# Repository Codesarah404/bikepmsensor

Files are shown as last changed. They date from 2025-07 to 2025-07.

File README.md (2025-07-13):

# bikepmsensor
This project presents a portable air quality monitoring system for bicycles. It measures PM2.5 and PM10 in real time and transmits the data via LoRaWAN, helping cyclists choose healthier routes based on current pollution levels.

This project was originally developed as part of a master's thesis at **HTW Berlin (University of Applied Sciences)** in 2025.

---

## 📡 Features

- Real-time PM2.5 / PM10 monitoring with HM3301
- GPS-based location via u-blox NEO-6M
- LoRaWAN transmission (TTN compatible)
- OLED display for live data (PM-values/risk based on WHO air quality limits)
- RGB-LED traffic light

---

## 🔧 Hardware Used

- Heltec WiFi LoRa 32 V2 (ESP32 + LoRa + OLED + charging)
- HM3303 fine dust sensor
- DHT22 temperature and humidity sensor
- u-blox NEO-6M GPS module
- RGB LED
- LiPo battery

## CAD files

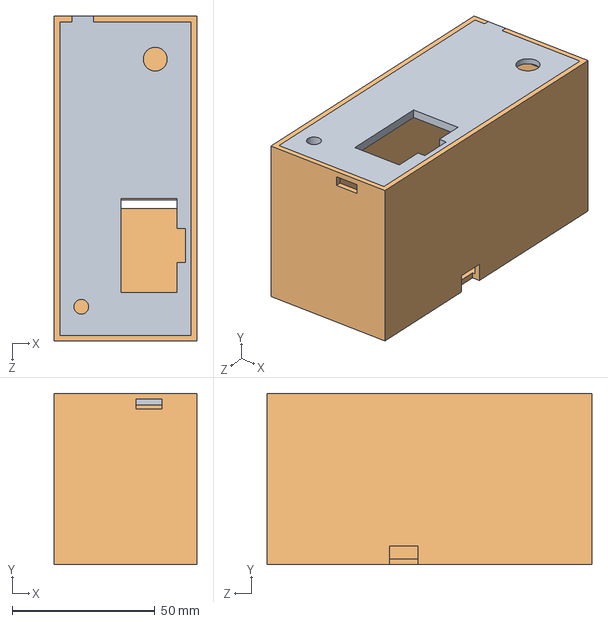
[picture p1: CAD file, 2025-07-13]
3d_printables/Gehäuse_gesamt.SLDASM
50.0 x 60.0 x 114.0 mm
Unterteil_Gehäuse
Oberteil_Gehäuse

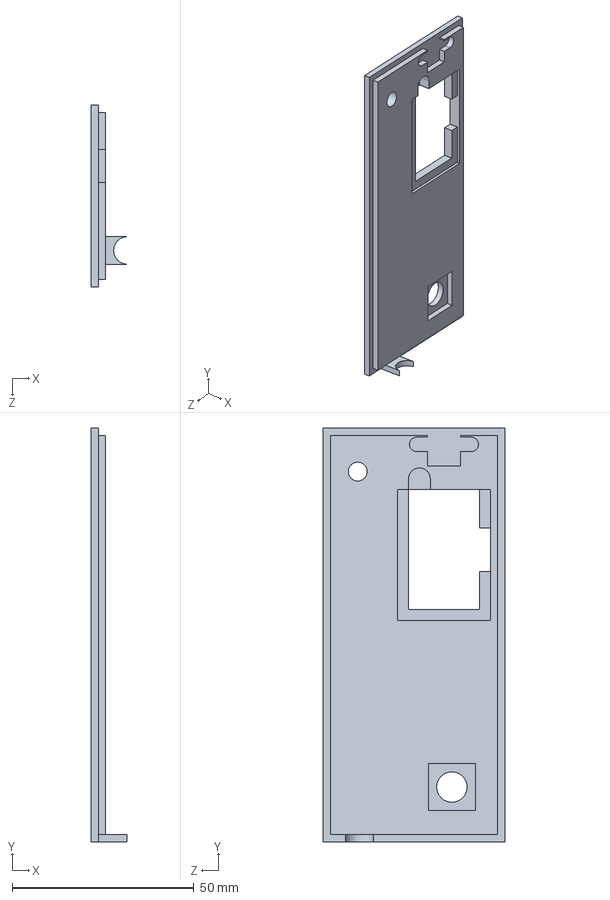
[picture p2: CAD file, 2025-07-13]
3d_printables/Oberteil_Gehäuse.SLDPRT
9.84 x 114.0 x 50.0 mm

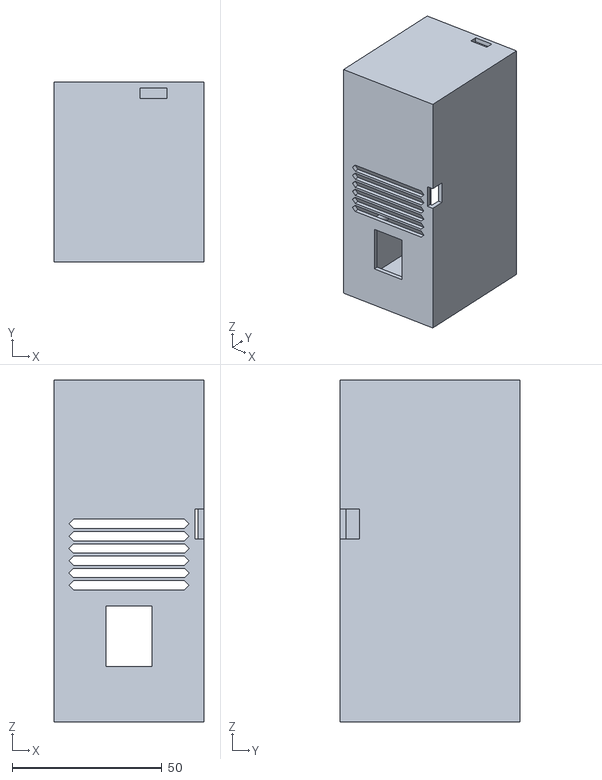
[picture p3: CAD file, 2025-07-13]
3d_printables/Unterteil_GehäuseV3.STL
50.0 x 60.0 x 114.0

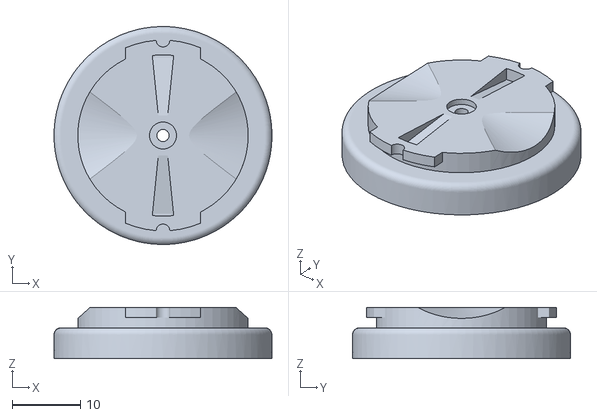
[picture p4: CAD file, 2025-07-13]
3d_printables/Garmin_Male_v2.STL
32.0 x 32.0 x 7.50

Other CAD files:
3d_printables/Oberteil_GehäuseV3.STL
3d_printables/Unterteil_Gehäuse.SLDPRT
3d_printables/Garmin_Male.SLDPRT

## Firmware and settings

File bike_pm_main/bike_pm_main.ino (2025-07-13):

/************************************************************************************************************************
Masterarbeit von Sarah Wauschkuhn,
Hochschule für Technik und Wirtschaft Berlin , 
2025

Hinweis: für das Projekt ist es im Vorfeld nötig einen Account bei TTN und Open Sensor Map anzulegen
TTN --> https://www.thethingsnetwork.org/docs/devices/registration/
Open Sensor Map --> https://opensensemap.org/register
Bitte prüfe deine LoRaWAN-Netzabdeckung für TTN -->  https://ttnmapper.org/heatmap/
Bitte prüfe bei Anpassung des Sendeintervalls, ob Fair Use Policy eingehalten wurde --> https://www.thethingsnetwork.org/airtime-calculator

Näheres hierzu ist in der dazugehörigen Masterthesis "Entwicklung eines Feinstaubmessgeräts für Radfahrende" zu finden.

Achtung ggf. C:\Users\name\Documents\Arduino\libraries\Heltec_ESP32_Dev-Boards\src\driver\sx1276.c in --> sx1276.c_backup umwandeln, macht sonst Probleme
************************************************************************************************************************/

//ESP32ChipID=9CD9A67A9834
// Basis-Bibliotheken für Arduino und Heltec
#include "Arduino.h"
#include <heltec.h>            // LoRa + OLED + ESP32-Funktionen (Heltec)

//für Heltec und Oled Display
#include "HT_SSD1306Wire.h"

//für HM3301 
#include <Tomoto_HM330X.h>
#include <Wire.h>

//für DHT11
#include <DHT.h>

//GPS
#include "HT_TinyGPS++.h"

//Lora
// LoRaWAN LMIC-Bibliotheken
#include <lmic.h>
#include <hal/hal.h>
#include <SPI.h>


//GPS
TinyGPSPlus gps;
//int year, month, day, hour, minute, second; //Zeit
double lat = 0.0, lon = 0.0; //Koordinaten
// GPS Pins definieren
#define GPS_RX 17  // Empfängt Daten vom GPS (GPS TX)
#define GPS_TX 12  // Sendet Daten an GPS (GPS RX)
HardwareSerial gpsSerial(2); // serial2 wird genutzt

// LoRa-Parameter (Europa)
// AppEUI, DevEUI und AppKey als Hex-Byte-Array (LSB-First)
static const u1_t PROGMEM APPEUI[8]  = { 0x00, 0x00, 0x00, 0x00, 0x00, 0x00, 0x00, 0x00 }; /* Füge eigene App EUI ein */ 
static const u1_t PROGMEM DEVEUI[8]  = { -, -, -, -, -, -, -, - }; /* Füge eigene Dev EUI ein, ist individuell und wird beim erstellen des Devices nach APPEUI generiert */ 
static const u1_t PROGMEM APPKEY[16] = { -, -, -, -, -, -, -, -,
                                         -, -, -, -, -, -, -, - }; /* Füge eigenen App Key ein */ 

const lmic_pinmap lmic_pins = {
  .nss = 18,      // LoRa_CS
  .rxtx = LMIC_UNUSED_PIN,
  .rst = 14,      // LoRa_RST
  .dio = {26, 35, 34}  // DIO0, DIO1, DIO2
};

static osjob_t sendjob;
//const unsigned TX_INTERVAL = 30; // ****Datenübertragung alle 30 Sekunden**** --> gut zum testen, doch kann das Netz schnell überlasten
//const unsigned TX_INTERVAL = 60; //****** Datenübertragung alle 60 Sekunden**** ---> Mittelweg, aber noch besser mehr Zeit geben
//const unsigned TX_INTERVAL = 120; // ****Datenübertragung alle 120 Sekunden****

unsigned long lastSensorRead = 0;
unsigned long lastDisplayUpdate = 0;
unsigned long lastSendTime = 0;

//Zeitmanagement, wichtig, da LoRa-Datenübertragung sehr getacktet ist. Die Prozesse des Devices müssen daher getaktet werden
const unsigned long sensorInterval = 5000;      // alle 5 Sekunden Sensoren auslesen
const unsigned long displayInterval = 2000;     // alle 2 Sekunden Display aktualisieren
const unsigned long sendInterval = 120000;      // alle 120 Sekunden senden

String loraStatusText = "";                // Text wie „Verbunden“, „Sende…“ etc.
unsigned long loraStatusTime = 0;          // Zeitpunkt der letzten Statusänderung
const unsigned long statusDisplayDuration = 4000;  // wie lange Status angezeigt wird (ms)

//HM330x - Feinstaub
//int pm1 = 0; //hierfür gibt es keine WHO Grenzwerte >> Falls doch gewünscht Programmversion mit pm1 wählen 
int pm25 = 0;
int pm10 = 0;
Tomoto_HM330X sensor;
//Achtung Standart für I2C kommunikation für heltec wifi lora v2! 
#define SDA 4
#define SCL 15

//DHT22
//#define DHT_PIN 13  > nicht verwenden Boot strap pin
#define DHT_PIN 25
#define DHT_TYPE DHT22       // DHT Typ, für DHT11 > #define DHT_TYPE DHT11   
DHT dht(DHT_PIN, DHT_TYPE);    // Initialisiere den DHT11 Sensor
float hum, temp;

//Warn-LED (RGB LED, Widerstände 120 OHM vor jedem PIN)
const int ledRotPin = 22;
const int ledGruenPin = 23;
const int ledBlauPin =13; 

//rotate only for GEOMETRY_128_64
#define SDA_OLED 4
#define SCL_OLED 15
#define RST_OLED 16
static SSD1306Wire  display(0x3c, 500000, SDA_OLED, SCL_OLED, GEOMETRY_128_64, RST_OLED); // addr , freq , i2c group , resolution , rst

//BitmapBild für Fahrrad erstellt mit GIMP
#define im_width 125
#define im_height 64
static unsigned char im_bits[] = {
   0xff, 0xff, 0xff, 0xff, 0xff, 0xff, 0xff, 0xff, 0xff, 0xff, 0xff, 0xff,
   0xff, 0xff, 0xff, 0x1f, 0xff, 0xff, 0xff, 0xff, 0xff, 0xff, 0xff, 0xff,
   0xff, 0xff, 0xff, 0xff, 0xff, 0xff, 0xff, 0x1f, 0xff, 0xff, 0xff, 0xff,
   0xff, 0xff, 0xff, 0xff, 0xff, 0xff, 0xff, 0xff, 0xff, 0xff, 0xff, 0x1f,
   0xff, 0xff, 0xff, 0xff, 0xff, 0xff, 0xff, 0xff, 0xff, 0xff, 0xcf, 0xff,
   0xff, 0xff, 0xff, 0x1f, 0xff, 0xff, 0xff, 0xff, 0xff, 0xff, 0xff, 0xff,
   0xff, 0xff, 0xc3, 0xff, 0xff, 0xff, 0xff, 0x1f, 0xff, 0xff, 0xff, 0xff,
   0xff, 0xff, 0xff, 0xff, 0xff, 0xff, 0xe1, 0xff, 0xff, 0xff, 0xff, 0x1f,
   0xff, 0xff, 0xff, 0xff, 0xff, 0xff, 0xff, 0xff, 0xff, 0x7f, 0xf0, 0xff,
   0xff, 0xff, 0xff, 0x1f, 0xff, 0xff, 0xff, 0xff, 0x1f, 0x00, 0xfe, 0xff,
   0xff, 0x3f, 0xfc, 0xff, 0xff, 0xff, 0xff, 0x1f, 0xff, 0xff, 0xff, 0xff,
   0x1f, 0x00, 0xfe, 0xff, 0xff, 0x1f, 0xfe, 0xff, 0xff, 0xff, 0xff, 0x1f,
   0xff, 0xff, 0xff, 0xff, 0x1f, 0x00, 0xfe, 0xff, 0xff, 0x1f, 0xff, 0xff,
   0xff, 0xff, 0xff, 0x1f, 0xff, 0xff, 0xff, 0xff, 0xff, 0xc7, 0xff, 0xff,
   0xff, 0x3f, 0xfe, 0xff, 0xff, 0xff, 0xff, 0x1f, 0xff, 0xff, 0xff, 0xff,
   0xff, 0xc7, 0xff, 0xff, 0xff, 0x3f, 0xfe, 0xff, 0xff, 0xff, 0xff, 0x1f,
   0xff, 0xff, 0xff, 0xff, 0xff, 0x8f, 0xff, 0xff, 0xff, 0x7f, 0xfe, 0xff,
   0xff, 0xff, 0xff, 0x1f, 0xff, 0xff, 0xff, 0xff, 0xff, 0x8f, 0xff, 0xff,
   0xff, 0x7f, 0xfc, 0xff, 0xff, 0xff, 0xff, 0x1f, 0xff, 0xff, 0xff, 0xff,
   0xff, 0x1f, 0xff, 0xff, 0xff, 0x7f, 0xfc, 0xff, 0xff, 0xff, 0xff, 0x1f,
   0xff, 0xff, 0xff, 0xff, 0xff, 0x1f, 0xff, 0xff, 0xff, 0x7f, 0xf8, 0xff,
   0xff, 0xff, 0xff, 0x1f, 0xff, 0xff, 0xff, 0xff, 0xff, 0x0f, 0xfe, 0xff,
   0xff, 0x3f, 0xf8, 0xff, 0xff, 0xff, 0xff, 0x1f, 0xff, 0xff, 0xff, 0xff,
   0xff, 0x0f, 0xfe, 0xff, 0xff, 0x3f, 0xf8, 0xff, 0xff, 0xff, 0xff, 0x1f,
   0xff, 0xff, 0xff, 0xff, 0xff, 0x47, 0xfc, 0xff, 0xff, 0x1f, 0xf1, 0xff,
   0xff, 0xff, 0xff, 0x1f, 0xff, 0xff, 0xff, 0xff, 0xff, 0xc7, 0xf8, 0xff,
   0xff, 0x8f, 0xf3, 0xff, 0xff, 0xff, 0xff, 0x1f, 0xff, 0xff, 0xff, 0xff,
   0xff, 0xe3, 0xf8, 0xff, 0xff, 0x87, 0xe3, 0xff, 0xff, 0xff, 0xff, 0x1f,
   0xff, 0xff, 0xff, 0xff, 0xff, 0xf3, 0xf1, 0xff, 0xff, 0xc7, 0xe3, 0xff,
   0xff, 0xff, 0xff, 0x1f, 0xff, 0xff, 0xff, 0x1f, 0xf8, 0xf1, 0xf3, 0xff,
   0xff, 0xe3, 0xc7, 0x81, 0xff, 0xff, 0xff, 0x1f, 0xff, 0xff, 0xff, 0x01,
   0x80, 0xf8, 0xe3, 0xff, 0xff, 0xf1, 0x07, 0x00, 0xf8, 0xff, 0xff, 0x1f,
   0xff, 0xff, 0x7f, 0x00, 0x00, 0xf8, 0xc7, 0xff, 0xff, 0xf1, 0x07, 0x00,
   0xe0, 0xff, 0xff, 0x1f, 0xff, 0xff, 0x1f, 0xf8, 0x1f, 0xf8, 0xc7, 0xff,
   0xff, 0xf8, 0x01, 0xff, 0x81, 0xff, 0xff, 0x1f, 0xff, 0xff, 0x0f, 0xff,
   0x7f, 0xf0, 0x8f, 0xff, 0x7f, 0xfc, 0x80, 0xff, 0x0f, 0xff, 0xff, 0x1f,
   0xff, 0xff, 0x87, 0xff, 0x3f, 0xe0, 0x8f, 0xff, 0x3f, 0x7e, 0x18, 0xff,
   0x1f, 0xfe, 0xff, 0x1f, 0xff, 0xff, 0xe3, 0xff, 0x3f, 0xc2, 0x1f, 0xff,
   0x3f, 0x3e, 0x1c, 0xff, 0x7f, 0xfc, 0xff, 0x1f, 0xff, 0xff, 0xf1, 0xff,
   0x1f, 0x8f, 0x1f, 0xff, 0x1f, 0x1f, 0x3f, 0xff, 0xff, 0xf8, 0xff, 0x1f,
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
  };


///////////////////////////////////////////////////////////////////////////////////////////////////////
//Startbildschirmprogramm1, Quelle: DrawingDemo der Heltec ESP32 Dev Boards Beispiele//////////////////
///////////////////////////////////////////////////////////////////////////////////////////////////////
void drawLines() {
  for (int16_t i=0; i<display.getWidth(); i+=4) {
    display.drawLine(0, 0, i, display.getHeight()-1);
    display.display();
    delay(10);
  }
  for (int16_t i=0; i<display.getHeight(); i+=4) {
    display.drawLine(0, 0, display.getWidth()-1, i);
    display.display();
    delay(10);
  }
  delay(250);

  display.clear();
}


///////////////////////////////////////////////////////////////////////////////////////////////////////
//Programmbildschirm - Anzeigesteuerung für OLED, ohne Lora-Status/////////////////////////////////////
///////////////////////////////////////////////////////////////////////////////////////////////////////
/*void showOLED(int pm25,int pm10, int hum, int temp){
    display.clear();
    display.setTextAlignment(TEXT_ALIGN_LEFT);
    display.setFont(ArialMT_Plain_10);

    //Feinstaubwerte festlegen
    display.drawString(0   , 0  ,   "PM");
    display.drawString(45  , 0  ,   "[ug/m^3]");
    display.drawString(0   , 16 ,   "PM2.5");
    display.drawString(56  , 16 ,   (String)pm25);
    display.drawString(0   , 32 ,   "PM10");
    display.drawString(56  , 32 ,   (String)pm10);

    //Risiko anzeigen
    display.drawString(94 , 0  ,  "RISIKO" );
    String pm25Risk = risikoPM25(pm25);
    display.drawString(94 , 16 ,    pm25Risk);
    String pm10Risk = risikoPM10(pm10);
    display.drawString(94 , 32 ,   pm10Risk);

    // Temperatur und Luftfeuchtigkeit anzeigen
    display.drawString(0   , 48 , "Temp: " + String((int)temp) + " °C");
    display.drawString(65   , 48 , "Hum: " + String((int)hum) + " %");

    //GPS ok, Lora ok, PM Failed ok
    //oder andere straße vorschlagen 
}*/

///////////////////////////////////////////////////////////////////////////////////////////////////////
//Programmbildschirm - Anzeigesteuerung für OLED, inklusive Lora-Status////////////////////////////////
///////////////////////////////////////////////////////////////////////////////////////////////////////
void showOLED(int pm25, int pm10, int hum, int temp) {
  display.clear();
  display.setTextAlignment(TEXT_ALIGN_LEFT); //Aussichtung 
  display.setFont(ArialMT_Plain_10); //Schriftart

  // Feinstaubwerte festlegen
  display.drawString(0   , 0  , "PM");
  display.drawString(45  , 0  , "[ug/m^3]");
  display.drawString(0   , 16 , "PM2.5");
  display.drawString(56  , 16 , (String)pm25);
  display.drawString(0   , 32 , "PM10");
  display.drawString(56  , 32 , (String)pm10);

  // Risiko anzeigen
  display.drawString(94 , 0  , "RISIKO");
  String pm25Risk = risikoPM25(pm25);
  display.drawString(94 , 16 , pm25Risk);
  String pm10Risk = risikoPM10(pm10);
  display.drawString(94 , 32 , pm10Risk);

  // Temperatur und Luftfeuchtigkeit anzeigen (leicht zusammengeschoben)
  //display.drawString(0   , 48 , "Temp: " + String((int)temp) + "°C");
  //display.drawString(60  , 48 , "Hum: " + String((int)hum) + "%");

  // -------- Temp, Hum 2. Version
  display.drawString(0   , 48 , "T: " + String((int)temp) + "°C");
  display.drawString(50  , 48 , "H: " + String((int)hum) + "%");

  /*//Variante 2 --- vorbereitet für Weiterentwicklung des Prototyps, verbesserte Fehlerbehandlung 
  // Feinstaubwerte festlegen
  display.drawString(0   , 0  , "PM");
  display.drawString(45  , 0  , "[ug/m^3]");

  // PM2.5
  display.drawString(0   , 16 , "PM2.5");
  display.drawString(56  , 16 , pm25 >= 0 ? String(pm25) : "---");

  // PM10
  display.drawString(0   , 32 , "PM10");
  display.drawString(56  , 32 , pm10 >= 0 ? String(pm10) : "---");

  // Risiko anzeigen
  display.drawString(94 , 0  , "RISIKO");
  display.drawString(94 , 16 , pm25 >= 0 ? risikoPM25(pm25) : "-");
  display.drawString(94 , 32 , pm10 >= 0 ? risikoPM10(pm10) : "-");

  // Temperatur und Luftfeuchtigkeit anzeigen
  display.drawString(0   , 48 , (temp >= -40 && temp <= 85) ? ("T: " + String((int)temp) + "°C") : "T: ---");
  display.drawString(50  , 48 , (hum >= 0 && hum <= 100) ? ("H: " + String((int)hum) + "%") : "H: ---");
  */


  // LoRa Status-Icon anzeigen, falls aktiv (rechts unten)
  if (millis() - loraStatusTime < statusDisplayDuration && loraStatusText != "") {
    display.setTextAlignment(TEXT_ALIGN_RIGHT);
    display.drawString(124, 48, getLoRaSymbol());  // Symbol z. B."..." oder "ok"
  }

  display.display();
}

///////////////////////////////////////////////////////////////////////////////////////////////////////
//Lorastatus für Programmbildschirm///////////////////////////////////////////////////////////////////
///////////////////////////////////////////////////////////////////////////////////////////////////////
String getLoRaSymbol() {
  if (loraStatusText.indexOf("Verbinde") >= 0) return "...";
  if (loraStatusText.indexOf("verbunden") >= 0) return "ok";
  if (loraStatusText.indexOf("fehlgeschl") >= 0) return "er";
  if (loraStatusText.indexOf("Sende") >= 0) return ">>";
  if (loraStatusText.indexOf("Upload") >= 0) return "up";
  return "no";
}

///////////////////////////////////////////////////////////////////////////////////////////////////////
// Funktion zur Bewertung des PM2.5-Risikos nach WHO-Richtlinien (2021)////////////////////////////////
///////////////////////////////////////////////////////////////////////////////////////////////////////
// Tagesmittelwerte:
// - ≤ 15 µg/m³ → gesundheitlich unbedenklich (grün)
// - 16–25 µg/m³ → leicht erhöhtes Risiko (gelb)
// - > 25 µg/m³ → gesundheitlich bedenklich (rot)
String risikoPM25(int pm25) {
  if (pm25 <= 15) {
    return "Niedrig";  // WHO-Grenzwert eingehalten
  } 
  else if (pm25 <= 25) {
    return "Mittel";   // Grenzwert leicht überschritten
  } 
  else {
    return "Hoch";     // Deutlich über WHO-Grenzwert
  }
}
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
void loop() {
  unsigned long now = millis();

  // GPS verarbeiten
  while (gpsSerial.available()) { //ist GPS da?
    gps.encode(gpsSerial.read());  // GPS-Daten kontinuierlich parsen (NMEA-Zeichenkette dekodieren)
  }
  if (gps.location.isValid()) { //sind die Daten gueltig?
    lat = gps.location.lat(); //Latitude extrahieren
    lon = gps.location.lng(); //Longitude extrahieren
  }

  // Sensoren auslesen
  if (now - lastSensorRead > sensorInterval) {
    lastSensorRead = now;

    // HM3301 auslesen
    if (!sensor.readSensor()) {
      Serial.println("HM3301 Fehler");
      pm25 = -1; //absichtlicher Fehler, da nicht möglich
      pm10 = -1; 
    } else {
      pm25 = sensor.std.getPM2_5(); //gibt int aus
      pm10 = sensor.std.getPM10(); //gibt int aus 
    }

    // DHT22 auslesen
    hum = dht.readHumidity();
    temp = dht.readTemperature();
    if (isnan(hum) || isnan(temp)) {
      hum = -1; //absichtlicher Fehler, unwahrscheinlich, dass alle Sensoren -1 ausgeben 
      temp = -1;
    }

    // RGB-LED-Farblogik zur visuellen Darstellung der Luftqualitätsstufen gemäß PM2.5- und PM10-Grenzwerten (WHO)
    if (pm25 <= 15 && pm10 <= 45) { //gruen
      digitalWrite(ledGruenPin, HIGH);
      digitalWrite(ledRotPin, LOW);
      digitalWrite(ledBlauPin, LOW);
    } else if (pm25 <= 25 && pm10 <= 75) {//gelb
      digitalWrite(ledGruenPin, HIGH);
      digitalWrite(ledRotPin, HIGH);
      digitalWrite(ledBlauPin, LOW);
    } else { //rot
      digitalWrite(ledGruenPin, LOW);
      digitalWrite(ledRotPin, HIGH);
      digitalWrite(ledBlauPin, LOW);
    }

    // Debug-Ausgabe
    /*Serial.print("GPS OK? "); Serial.println(gps.location.isValid() ? "JA" : "NEIN");
    Serial.print("PM2.5: "); Serial.println(pm25);
    Serial.print("PM10: "); Serial.println(pm10);
    Serial.print("Temp: "); Serial.println(temp);
    Serial.print("Hum: "); Serial.println(hum);
    Serial.print("Lat: "); Serial.println(lat, 6);
    Serial.print("Lon: "); Serial.println(lon, 6);
    Serial.print("Satelliten: "); Serial.println(gps.satellites.value());
    Serial.print("HDOP: "); Serial.println(gps.hdop.hdop());*/
  }

  // OLED-Anzeige aktualisieren, wenn das Intervall überschritten ist
  /*now -               Zeit die seit Start von millis() vergangen ist
   lastDisplayUpdate -  Der Zeitpunkt (in ms), an dem das Display zuletzt aktualisiert wurde
   displayIntervall -   Zeitpunkt wann Display das letzte mal aktualisiert wurde*/
  if (now - lastDisplayUpdate > displayInterval) {
    lastDisplayUpdate = now; 
    showOLED(pm25, pm10, hum, temp); // Sensorwerte auf dem Display anzeigen
    //display.display();
  }

  // LoRaWAN Daten senden
  if (now - lastSendTime > sendInterval) { // Prueft, ob seit dem letzten Sendezeitpunkt genug Zeit vergangen ist (Intervallsteuerung).
    lastSendTime = now; // Zeitstempel aktualisieren, um Intervallsteuerung zu ermoeglichen; verhindert mehrfaches Senden im selben Intervall
    do_send(&sendjob); // Sendevorgang starten: Payload wird vorbereitet und ueber LoRaWAN uebertragen; uebergibt einen Auftrag an LMIC, um Sensordaten als Payload ueber LoRaWAN zu uebertragen.
  }

  /*
  // Weiterentwicklung um Fehlerhafte Weiterleitung an OSEM auszuschließen
    // Prüfung auf die -1 bei ALLEN Sensoren vorliegt
    bool all_invalid = 
      (pm25 == -1) &&
      (pm10 == -1) &&
      (temp == -1) &&
      (hum == -1);

  if (now - lastSendTime > sendInterval) {
    lastSendTime = now;
    if (!all_invalid) {
        do_send(&sendjob);
    } else {
        Serial.println("Alle Sensorwerte ungültig, keine LoRa-Übertragung."); //Sendevorgang verhindern, falls ungültige Werte --> da Kontaktfehler; noch am Starten etc. 
    }
  }*/

  // LMIC weiterlaufen lassen
  os_runloop_once(); 
}

///////////////////////////////////////////////////////////////////////////////////////////////////////
// LMIC Sende-Funktion/////////////////////////////////////////////////////////////////////////////////
///////////////////////////////////////////////////////////////////////////////////////////////////////
void do_send(osjob_t* j) {
  if (LMIC.opmode & OP_TXRXPEND) { //Abfrage ob der LoRaWAN-Stack aktuell mit Senden oder Empfangen beschaeftigt ist (OP_TXRXPEND ist ein Bit-Flag)
    Serial.println("LoRa TX läuft noch...");
  } else {
    // Payload vorbereiten
    byte payload[14];  // 2x PM, 1x Temp, 1x RH, 2x GPS à 4 Bytes = 14

    // Feinstaub (PM2.5 & PM10)
    payload[0] = pm25 >> 8; //oberes Byte von pm25; ... >> N: Rechtsverschiebung – holt das Byte an Position N
    payload[1] = pm25 & 0xFF; //unteres Byte von pm25; ... & 0xFF: Maskiert alle Bits außer den unteren 8 (ein Byte)
    payload[2] = pm10 >> 8; //oberes Byte von pm10
    payload[3] = pm10 & 0xFF; //unteres Byte von pm10

    // Temperatur & Luftfeuchtigkeit (nur ganzzahlig, je 1 Byte)
    payload[4] = (int)temp;
    payload[5] = (int)hum;

    // GPS-Koordinaten in Mikrograd umwandeln
    int32_t lat_bin = lat * 1e6;  // z.B. 52.520008 → 52520008
    int32_t lon_bin = lon * 1e6;

    // Latitude (Big Endian)
    payload[6]  = (lat_bin >> 24) & 0xFF;// Byte 1 (höchstes)
    payload[7]  = (lat_bin >> 16) & 0xFF;
    payload[8]  = (lat_bin >> 8)  & 0xFF;
    payload[9]  =  lat_bin        & 0xFF;// Byte 4 (niedrigstes)

    // Longitude (Big Endian)
    payload[10] = (lon_bin >> 24) & 0xFF;// Byte 1 (höchstes)
    payload[11] = (lon_bin >> 16) & 0xFF;
    payload[12] = (lon_bin >> 8)  & 0xFF;
    payload[13] =  lon_bin        & 0xFF;// Byte 4 (niedrigstes)

    // Senden
    /*  1: LoRaWAN-Portnummer (in TTN entsprechend zugeordnet, z.B. für einen Payload-Decoder).
        payload: Pointer auf das zu sendende Byte-Array.
        sizeof(payload): Länge des Payloads in Bytes (hier 14).
        0: Unbestätigte Übertragung (kein ACK erforderlich) >> siehe TTN Fair Policy, sonst weniger Airtime am Tag moeglich*/
    LMIC_setTxData2(1, payload, sizeof(payload), 0);
    Serial.println("LoRaWAN Daten gesendet");
  }
}


///////////////////////////////////////////////////////////////////////////////////////////////////////
//Lora Event Handler///////////////////////////////////////////////////////////////////////////////////
///////////////////////////////////////////////////////////////////////////////////////////////////////
/*Event-Handler für die LoRaWAN-Bibliothek LMIC. Sie wird automatisch aufgerufen, wenn das LoRa-Modem 
ein bestimmtes Ereignis (event) meldet –z. B. Verbindungsaufbau, Datenübertragung, Fehlermeldung. 
Hier wird auf die verschiedenen LMIC-Ereignisse reagiert und entsprechende Meldungen auf dem seriellen
Monitor ausgegeben.*/
void onEvent(ev_t ev) {
  Serial.print("LMIC Event: ");
  Serial.println(ev); //gibt numerischen Wert des Events zur Diagnose aus

  switch (ev) {
    case EV_JOINING:
      Serial.println("Beitritt zu TTN läuft...");
      loraStatusText = "Verbinde mit TTN...";
      loraStatusTime = millis();
      break;

    case EV_JOINED:
      Serial.println("Erfolgreich mit TTN verbunden!");
      loraStatusText = "TTN verbunden";
      loraStatusTime = millis();
      // Optionale Link Check Abschaltung:
      LMIC_setLinkCheckMode(0);
      break;

    case EV_JOIN_FAILED:
      Serial.println("Beitritt zu TTN fehlgeschlagen!");
      loraStatusText = "TTN Join fehlgeschl";
      loraStatusTime = millis();
      break;

    case EV_TXSTART:
      Serial.println("Sende Daten...");
      loraStatusText = "Sende";
      loraStatusTime = millis();
      break;

    case EV_TXCOMPLETE:
      Serial.println("Datenübertragung abgeschlossen.");
      loraStatusText = "Upload";
      loraStatusTime = millis();
      break;

    case EV_TXCANCELED:
      Serial.println("Senden abgebrochen!");
      loraStatusText = "Senden abgebrochen";
      loraStatusTime = millis();
      break;

    case EV_REJOIN_FAILED:
      Serial.println("Rejoin fehlgeschlagen!");
      loraStatusText = "Rejoin fehlgeschl";
      loraStatusTime = millis();
      break;

    default:
      Serial.println("Anderes LoRaWAN Ereignis");
      loraStatusText = "LoRa Event: " + String(ev);
      loraStatusTime = millis();
      break;
  }
}
